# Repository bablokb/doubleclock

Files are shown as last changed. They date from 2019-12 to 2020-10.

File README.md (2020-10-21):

Kitchen-Clock with two countdown-timers (based on TM1637-displays)
==================================================================

Overview
--------

This project implements a double countdown clock (kitchen-timer) using
two TM1637 displays (and some additional components, see below).

The "firmware" uses Python3 and is expected to run on a Raspberry Pi Zero
(or a similar SBC). Porting to a MCU should be an easy task if you have
enough experience.

Hardware
--------

The setup uses the following hardware-components:

  - two TM1637 clock displays
  - one 5-way button for setup
  - one normal button for start/stop
  - optional up to four normal buttons for save/restore ("memory"-buttons)
  - one slider
  - one active buzzer

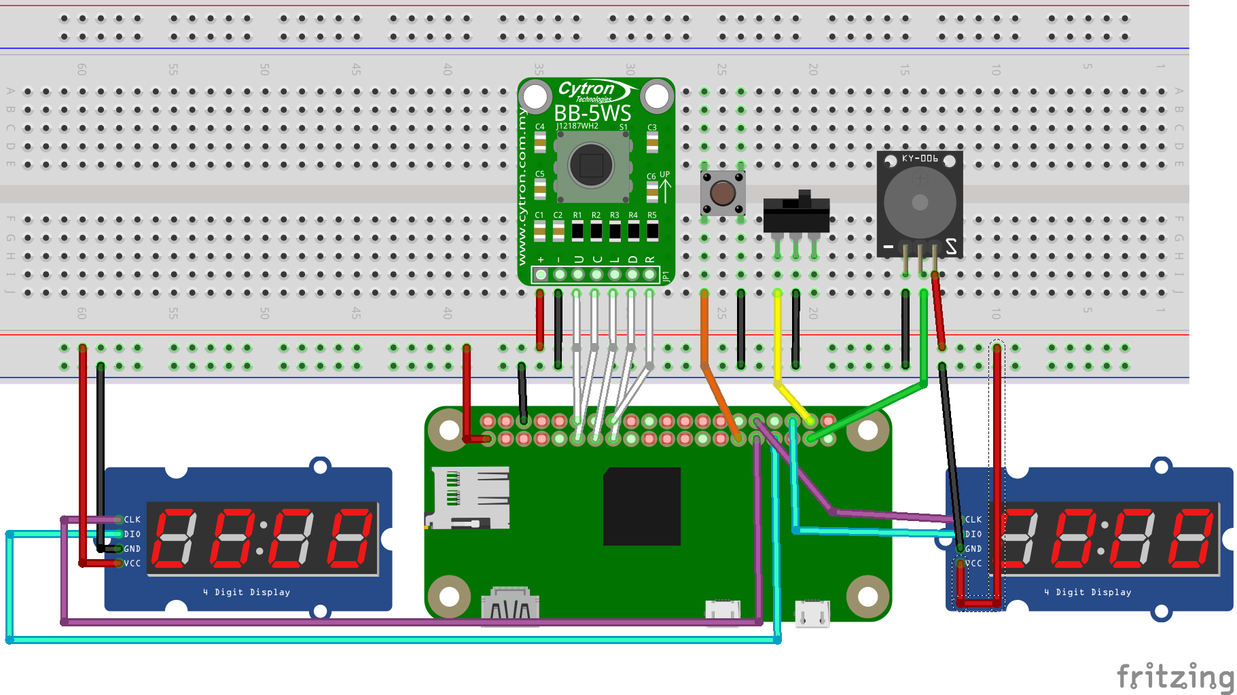
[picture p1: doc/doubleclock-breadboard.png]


You can find details on the necessary wiring in `doc/specs.md`.

This is a prototype using a
[https://github.com/bablokb/pi-proto-hat](https://github.com/bablokb/pi-proto-hat)
as basis:

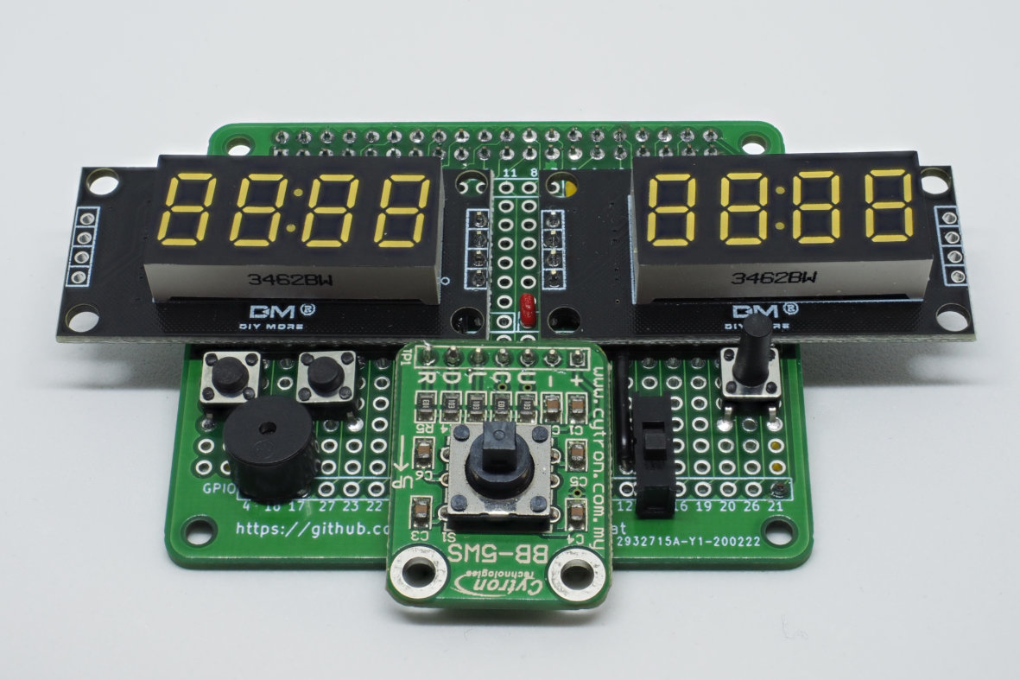
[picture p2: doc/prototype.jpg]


Final version of the case:

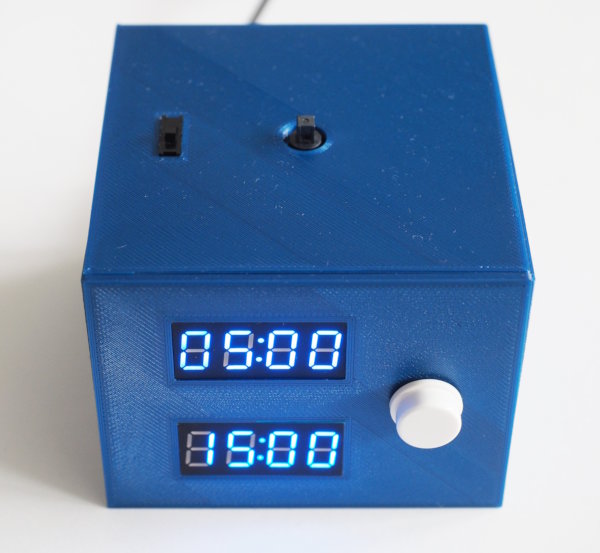
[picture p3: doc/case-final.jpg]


Software
--------

Run

    git clone https://github.com/bablokb/doubleclock.git
    cd doubleclock
    sudo tools/install

to install the software and some prerequisite packages. This will also enable
a systemd-service so that the clock starts at boot-time.

System-Tweaks
-------------

The clock has no shutdown button, so it is best to configure the system
as a readonly-system. If you have a dedicated Pi for the clock, just remove
the lines from `/etc/fstab` which mount `/` and `/boot`.

To speedup boot-time, disable the keyboard-setup.service. Also, add "quiet"
to `/boot/cmdline.txt`. Of course you have to do this before the system is
in readonly-mode.

In readonly-mode, saving the last state and the memory-buttons don't work.
If you want a readonly-system *and* memory-buttons, create a small
data-partition, mount it in `/etc/fstab` with the option `sync` and
replace `/var/lib/doubleclock` with a symbolic link to your mounted
data-partition.

Usage
-----

Push the 5-way button down to enable or disable setup-mode. In setup-mode the
active digit of the active clock will blink. Use the slider to switch between
clocks. Pushing the button to the left or right will change the active digit,
pushing it up or down will change the value. After setting the alarm-times,
push the button down again to leave setup-mode. Note that pressing the
start/stop-button in setup-mode will reset all values to zero.

Use the start/stop-button to activate the countdown. As soon as a clock
reaches zero, the buzzer will start and the brightness of the display is
reduced. Note that after the alarm starts, the display will continue to
count.

In alarm-mode, the start/stop-button will stop the buzzer, but not the second
running clock. Stopping the second alarm will reset the values to the state
after the last setup.

Pressing a memory-button in setup-mode will save the current values. Pressing
them in ready-mode will recall the values. Independent of the memory-buttons,
the clock will save the last values of the clocks.

Case
----

A case (housing) is now available. You can find my tinkercad-project with various parts
[here](https://www.tinkercad.com/things/8dUa6ugfUpZ). You probably need to adapt the
individual parts to your specific components (e.g. to the dimension of your
slider-switch).

The case uses PETG, since PLA is not usable in moist environments like a
kitchen. Also, care has to be taken that no electronic components get wet
when water is spilled on the table. Ideally, the clock would be wall-mounted,
but this is not always possible.

The case should also be easy to open and close, in case a component needs
to be replaced. There are too many throw-away gadgets out in the wild, which
stop working only because a wire gets loose and there is no way to open
the gadget without destroying it. The current case design does not fully meet
these goals.

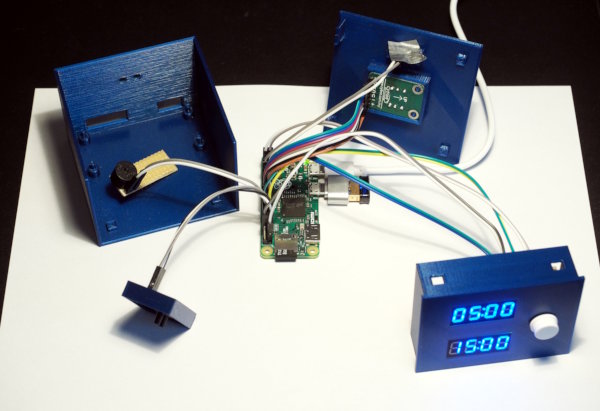
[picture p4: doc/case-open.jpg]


One off the biggest challenges is how to attach the components in a
stable manner. Most of them have either no support at all, or their
mounting holes would result in the breakout to be on the outside.

License
-------

The code in `files/usr/local/sbin/doubleclock.py` is licensed under the GPLv3.

The library in `files/usr/local/sbin/TM1637.py` is from
[https://github.com/bablokb/circuitpython-tm1637](https://github.com/bablokb/circuitpython-tm1637)
and is distributed under a MIT-license.

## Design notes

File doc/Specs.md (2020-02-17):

Technical Specifications
========================

Operation
---------

The *slider* changes between the two clocks. The 5-way button changes the
clock values. The *start/stop* button starts and stops the countdown and
turns of the buzzer. A long press of *start/stop* resets both clocks.

Up to four memory buttons save/recall the current values. Pressing a
memory button while in setup-state will save the values. Pressing the button
in ready-state will recall the values.

The clocks display a countdown in the format "MM:SS" with MM ranging from
0-99 and seconds from 0-59.

States
------

Possible states:

  - *init*: both clocks show "00:00"
  - *setup*: one digit of the active clock is blinking
  - *ready*: one or both clocks are ready to run
  - *running*: one or both clocks are running
  - *alarm*: the buzzer is ringing

Transitions
-----------

  - *init*    + *set/push*   -> *setup*
  - *setup*   + *set/push*   -> *ready*
  - *setup*   + *left/right* -> *setup* (change digit)
  - *setup*   + *up/down*    -> *setup* (increase/decrease value of digit)
  - *setup*   + *start*      -> *init*
  - *ready*   + *start/stop* -> *running*
  - *running* + *start/stop* -> *ready*
  - *alarm*   + *start/stop* -> *running* (stop buzzer) or *ready*

Pin Configuration
-----------------

This is just for information and might not be up-to-date. The truth is
in the code (file `doubleclock.py`).

| Function | Pi-Zero |
|---|---|
| set (push) | 17 |
| up | 18 |
| down | 22 |
| left | 27 |
| right | 23 |
| slider (left) | 20 |
| start/stop | 05 |
| clock (left,clk)  | 06 |
| clock (left,dio)  | 13 |
| clock (right,clk) | 12 |
| clock (right,dio) | 16 |
| buzzer | 26 |
| mem1 | 09 |
| mem2 | 25 |
| mem3 | 11 |
| mem4 | 08 |

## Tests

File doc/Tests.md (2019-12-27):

Tests
=====

  * startup: all digits show 0 (ok)
  * push: rightmost digits blinks on the side of the slider (ok)
  * up/down: blinking digit changes value (ok)
  * left/right: blinking digit moves left/right (ok)
  * slider: blinking digit changes side (ok)
  * slider: blinking digit changes back (ok)
  * start during setup: clear all values and reset (ok)
  * push: digits stop blinking (ok)
  * start: countdown starts (ok)
  * start (again): cancel countdown, show alarm-times (ok)
  * alarm1 on + start: stop buzzer, countdown continues (ok)
  * alarm1 on: buzzer stops automatically (ok)
  * alarm2 on + start: stop buzzer, show alarm-times (ok)
  * single alarm countdown left: countdown, alarm, auto-stop (ok)
  * single alarm countdown rigt: countdown, alarm (ok)

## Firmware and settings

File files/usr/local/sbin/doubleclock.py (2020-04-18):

#!/usr/bin/python3
# -*- coding: utf-8 -*-
# ----------------------------------------------------------------------------
# Countdown-clock with two clocks
#
# Author: Bernhard Bablok
# License: GPL3
#
# Website: https://github.com/bablokb/doubleclock
#
# ----------------------------------------------------------------------------

import threading, signal, os, sys, time, pickle
import TM1637
import board
import RPi.GPIO as GPIO

# --- file for persistent configuration   ------------------------------------

DATA_DIR = "/var/lib/doubleclock"

# --- pin-configuration   ----------------------------------------------------

PIN_PUSH      = 17
PIN_UP        = 18
PIN_DOWN      = 22
PIN_LEFT      = 27
PIN_RIGHT     = 23
PIN_SLIDER_L  = 20
PIN_START     =  5

# set values to zero if unused
PIN_MEM1      =  9
PIN_MEM2      = 25
PIN_MEM3      = 11
PIN_MEM4      =  8

PIN_LCLOCK_C  = board.D6
PIN_LCLOCK_D  = board.D13
PIN_RCLOCK_C  = board.D12
PIN_RCLOCK_D  = board.D16

PIN_BUZZER    = 26
PIN_BUZZER_ON = GPIO.LOW                   # change to GPIO.HIGH if necessary

# --- application-class   ----------------------------------------------------

class DoubleClock(object):

  _STATE_INIT    = 0
  _STATE_SETUP   = 1
  _STATE_READY   = 2
  _STATE_RUNNING = 3
  _STATE_ALARM   = 4
  _BUZZ_WARN     = (0.25,1)                # (duration,repeat)
  _BUZZ_ALARM    = [(0.25,20),(0.5,-1)]    # second alarm runs indefinitely
  _BRIGHTNESS    = 7                       # maximum brightness
  
  # --- constructor   --------------------------------------------------------

  def __init__(self):
    """ constructor """

    self._exit_ev  = threading.Event()         # exit event
    self._count_ev = threading.Event()         # countdown
    self._buzz_ev  = threading.Event()         # buzzer
    self._buzz_thread  = None
    self._clocks   = [                         # left-clock: index is 0
        TM1637.TM1637(PIN_LCLOCK_C,PIN_LCLOCK_D),
        TM1637.TM1637(PIN_RCLOCK_C,PIN_RCLOCK_D)
      ]

    GPIO.setmode(GPIO.BCM)

    GPIO.setup(PIN_PUSH,     GPIO.IN)
    GPIO.setup(PIN_UP,       GPIO.IN)
    GPIO.setup(PIN_DOWN,     GPIO.IN)
    GPIO.setup(PIN_LEFT,     GPIO.IN)
    GPIO.setup(PIN_RIGHT,    GPIO.IN)
    GPIO.setup(PIN_SLIDER_L, GPIO.IN,  pull_up_down=GPIO.PUD_UP)
    GPIO.setup(PIN_START,    GPIO.IN,  pull_up_down=GPIO.PUD_UP)
    GPIO.setup(PIN_BUZZER,   GPIO.OUT, initial=1-PIN_BUZZER_ON)

    GPIO.add_event_detect(PIN_PUSH,     GPIO.FALLING,      self.on_push)
    GPIO.add_event_detect(PIN_UP,       GPIO.FALLING,        self.on_up)
    GPIO.add_event_detect(PIN_DOWN,     GPIO.FALLING,      self.on_down)
    GPIO.add_event_detect(PIN_LEFT,     GPIO.FALLING,      self.on_left)
    GPIO.add_event_detect(PIN_RIGHT,    GPIO.FALLING,     self.on_right)
    GPIO.add_event_detect(PIN_SLIDER_L, GPIO.BOTH,       self.on_slider)
    GPIO.add_event_detect(PIN_START,    GPIO.FALLING, self.on_start,200)

    for pin in [PIN_MEM1,PIN_MEM2,PIN_MEM3,PIN_MEM4]:
      if pin:
        GPIO.setup(pin,GPIO.IN,pull_up_down=GPIO.PUD_UP)
        GPIO.add_event_detect(pin,GPIO.FALLING, self.on_mem,200)

    self._reset()
    self._restore()

  # --- reset internal state   -----------------------------------------------

  def _reset(self):
    self._state    = DoubleClock._STATE_INIT   # global state
    self._values   = [[0,0,0,0], [0,0,0,0]]    # digit-values
    self._dig_nr   = [0,0]                     # current digit-number
    self._clock_nr = GPIO.input(PIN_SLIDER_L)  # current "active" clock
    
  # --- restore clock-values from persistent storage   -----------------------

  def _restore(self,pin=None):
    if pin:
      data_file = os.path.join(DATA_DIR,"mem%d.data" % pin)
    else:
      data_file = os.path.join(DATA_DIR,"last.data")
    try:
      with open(data_file,"rb") as f:
        self._values = pickle.load(f)
    except:
      pass
    if self._values != [[0,0,0,0],[0,0,0,0]]:
      self._state = DoubleClock._STATE_READY
      if pin:
        self._save()

  # --- save clock-values to persistent storage   ----------------------------

  def _save(self,pin=None):
    """ save values - might fail if system is read-only """
    if pin:
      data_file = os.path.join(DATA_DIR,"mem%d.data" % pin)
    else:
      data_file = os.path.join(DATA_DIR,"last.data")
    try:
      with open(data_file,"wb") as f:
        pickle.dump(self._values,f)
    except:
      pass

  # --- process set (push)   -------------------------------------------------

  def on_push(self,pin):
    if self._state == DoubleClock._STATE_INIT:
      self._state = DoubleClock._STATE_SETUP
    elif self._state == DoubleClock._STATE_SETUP:
      self._save()
      self._state = DoubleClock._STATE_READY
    elif self._state == DoubleClock._STATE_READY:
      self._state = DoubleClock._STATE_SETUP

  # --- process left   -------------------------------------------------------

  def on_left(self,pin):
    if not self._state == DoubleClock._STATE_SETUP:
      self.buzz(*DoubleClock._BUZZ_WARN)
    else:
      self._dig_nr[self._clock_nr] = (self._dig_nr[self._clock_nr] + 1) % 4

  # --- process right   ------------------------------------------------------

  def on_right(self,pin):
    if not self._state == DoubleClock._STATE_SETUP:
      self.buzz(*DoubleClock._BUZZ_WARN)
    else:
      self._dig_nr[self._clock_nr] = (self._dig_nr[self._clock_nr] + 3) % 4

  # --- process up   ---------------------------------------------------------

  def on_up(self,pin):
    if not self._state == DoubleClock._STATE_SETUP:
      self.buzz(*DoubleClock._BUZZ_WARN)
      return

    clock = self._clock_nr
    digit = self._dig_nr[clock]
    old   = self._values[clock][digit]
    if digit == 1:
      # 10-seconds
      self._values[clock][digit] = (old+1) % 6
    else:
      # 1-seconds, 1-minutes, 10-minutes
      self._values[clock][digit] = (old+1) % 10

  # --- process down   -------------------------------------------------------

  def on_down(self,pin):
    if not self._state == DoubleClock._STATE_SETUP:
      self.buzz(*DoubleClock._BUZZ_WARN)
      return

    clock = self._clock_nr
    digit = self._dig_nr[clock]
    old   = self._values[clock][digit]
    if digit == 1:
      # 10-seconds
      self._values[clock][digit] = (old+5) % 6
    else:
      # 1-seconds, 1-minutes, 10-minutes
      self._values[clock][digit] = (old+9) % 10

  # --- process start   ------------------------------------------------------

  def on_start(self,pin):
    if self._state == DoubleClock._STATE_INIT:
      # not supported, just buzz
      self.buzz(*DoubleClock._BUZZ_WARN)

    elif self._state == DoubleClock._STATE_SETUP:
      # reset digits during setup-mode
      self._reset()
      self._save()

    elif self._state == DoubleClock._STATE_READY:
      # start alarms

      # calculate seconds per clock ...
      self._secs = [0,0]
      for i in range(2):
        self._secs[i] = (10*60*self._values[i][3] + 60*self._values[i][2] +
                         10*self._values[i][1] +    self._values[i][0])
      
      if self._secs[0] + self._secs[1] > 0:
        self._count_ev.clear()
        self._state    = DoubleClock._STATE_RUNNING
        # ... and start alarm-thread
        threading.Thread(target=self._count).start()

    elif self._state == DoubleClock._STATE_RUNNING:
      # stop countdown and reset to ready-state
      self._count_ev.set()
      self._state = DoubleClock._STATE_READY

    elif self._state == DoubleClock._STATE_ALARM:
      # turn off buzzer
      self._buzz_ev.set()
      if self._secs[0] <= 0 and self._secs[1] <= 0:
        # both alarms are finished, so stop count-down
        self._state = DoubleClock._STATE_READY
        self._count_ev.set()
      else:
        # one alarm is still running
        self._state = DoubleClock._STATE_RUNNING

  # --- process exit   -------------------------------------------------------

  def on_exit(self):
    self._count_ev.set()
    self._buzz_ev.set()
    self._exit_ev.set()

  # --- process slider   -----------------------------------------------------

  def on_slider(self,pin):
    self._clock_nr = GPIO.input(PIN_SLIDER_L)

  # --- process memx-buttons   -----------------------------------------------

  def on_mem(self,pin):
    if self._state == DoubleClock._STATE_SETUP:
      # save values to mem-pinnr
      self._save(pin)
    elif (self._state == DoubleClock._STATE_INIT or
                                     self._state == DoubleClock._STATE_READY):
      self._restore(pin)
    else:
      # not supported, just buzz
      self.buzz(*DoubleClock._BUZZ_WARN)

  # --- ring the buzzer   ----------------------------------------------------

  def buzz(self,duration,count=1):
    if self._buzz_thread:                # buzzer already buzzing
      return
    self._buzz_ev.clear()
    self._buzz_thread = threading.Thread(
      target=self._buzz,args=(duration,count))
    self._buzz_thread.start()

  # --- run the main thread   ------------------------------------------------

  def run(self):
    threading.Thread(target=dclock._update).start()

  # --- update the clock-chips   ---------------------------------------------

  def _update(self):
    """ we update every 0.5 secs to implement blinking """

    blink_off = False
    while True:
      t1 = time.monotonic()
      if self._state in [DoubleClock._STATE_ALARM,DoubleClock._STATE_RUNNING]:
        # update using self._secs
        for i in [0,1]:
          (m,s) = divmod(abs(self._secs[i]),60)
          self._clocks[i].numbers(m,s)
          if not self._secs[i]:
            # timer reached zero, so dim display
            self._clocks[i].brightness(0)
      else:
        # update using self._values
        for i in [0,1]:
          self._clocks[i].brightness(DoubleClock._BRIGHTNESS)
          # copy array of int to array of strings
          val = [str(self._values[i][j]) for j in range(3,-1,-1)]
          if (self._state == DoubleClock._STATE_SETUP and blink_off and
                                                          self._clock_nr == i):
            # the current digit of active clock will blink
            val[3-self._dig_nr[i]] = " "
          digits = "%s%s%s%s" % (*val,)
          self._clocks[i].show(digits,True)
        blink_off = not blink_off

      # wait up to 0.5 seconds (take time lost in logic into account)
      delay = max(0.0,0.5-(time.monotonic()-t1))
      if self._exit_ev.wait(delay):
        break

    # cleanup (clear displays)
    for i in [0,1]:
      self._clocks[i].show(" "*4,False)

  # --- ring the buzzer   ----------------------------------------------------

  def _buzz(self,duration,count):
    """ passing count=-1 will sound the buffer indefintely """

    while count != 0:
      GPIO.output(PIN_BUZZER,PIN_BUZZER_ON)   # buzzer on
      if self._buzz_ev.wait(duration):        # wait and check for interrupt
        break
      GPIO.output(PIN_BUZZER,1-PIN_BUZZER_ON) # buzzer off
      if self._buzz_ev.wait(duration):        # wait and check for interrupt
        break
      count -= 1
    GPIO.output(PIN_BUZZER,1-PIN_BUZZER_ON)   # buzzer off
    self._buzz_thread = None

  # --- count down the remaining seconds   -----------------------------------

  def _count(self):
    """ count down both clocks, exit on external event """

    # we don't want to count-down a clock which is already 0 at start
    use_clock = [self._secs[0] > 0, self._secs[1] > 0]

    # count-down the seconds and sleep inbetween
    while True:
      t1 = time.monotonic()
      if self._state in [DoubleClock._STATE_ALARM,DoubleClock._STATE_RUNNING]:
        for i in [0,1]:
          if use_clock[i]:
            self._secs[i] -= 1
            if not self._secs[i]:
              # countdown reached zero, so stop old and start new alarm
              if self._buzz_thread:
                self._buzz_ev.set()
                try:
                  self._buzz_thread.join()
                except:
                  pass
              self._state = DoubleClock._STATE_ALARM
              self.buzz(*DoubleClock._BUZZ_ALARM[i])

      # wait up to one second (take time lost in logic into account)
      delay = max(0.0,1-(time.monotonic()-t1))

      if self._count_ev.wait(delay):
        return

# --------------------------------------------------------------------------

def signal_handler(_signo, _stack_frame):
  """ Signal-handler to cleanup threads """

  global dclock
  dclock.on_exit()
  sys.exit(0)

# --------------------------------------------------------------------------

if __name__ == "__main__":

  # create objects and run update thread
  dclock = DoubleClock()
  dclock.run()

  # setup signal handlers
  signal.signal(signal.SIGTERM, signal_handler)
  signal.signal(signal.SIGINT, signal_handler)

  # --- main loop   ---------------------------------------------------------

  signal.pause()

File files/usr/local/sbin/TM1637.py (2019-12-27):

"""
MicroPython TM1637 quad 7-segment LED display driver
https://github.com/mcauser/micropython-tm1637

MIT License
Copyright (c) 2016 Mike Causer

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
import digitalio
import time

class TM1637(object):
  """Library for quad 7-segment LED modules based on the TM1637 LED driver."""

  _CMD1   = 0x40      # data command
  _CMD2   = 0xC0      # address command
  _CMD3   = 0x80      # display control command
  _DSP_ON = 0x08      # display on
  _DELAY  = 0.000010  # 10us delay between clk/dio pulses
  _MSB    = 0x80      # decimal point or colon depending on your display

  # 0-9, a-z, blank, dash, star
  _SEGMENTS = bytearray(b'\x3F\x06\x5B\x4F\x66\x6D\x7D\x07\x7F\x6F\x77\x7C\x39\x5E\x79\x71\x3D\x76\x06\x1E\x76\x38\x55\x54\x3F\x73\x67\x50\x6D\x78\x3E\x1C\x2A\x76\x6E\x5B\x00\x40\x63')

  def __init__(self, clk, dio, brightness=7):
    if not 0 <= brightness <= 7:
      raise ValueError("Brightness out of range")
    self._brightness = brightness

    self._clk = digitalio.DigitalInOut(clk)
    self._clk.direction = digitalio.Direction.OUTPUT
    self._clk.value     = 0
    self._dio = digitalio.DigitalInOut(dio)
    self._dio.direction = digitalio.Direction.OUTPUT
    self._dio.value     = 0
    time.sleep(TM1637._DELAY)
    self._write_data_cmd()
    self._write_dsp_ctrl()

  def _start(self):
    self._dio.value = 0
    time.sleep(TM1637._DELAY)
    self._clk.value = 0
    time.sleep(TM1637._DELAY)

  def _stop(self):
    self._dio.value = 0
    time.sleep(TM1637._DELAY)
    self._clk.value = 1
    time.sleep(TM1637._DELAY)
    self._dio.value = 1

  def _write_data_cmd(self):
    # automatic address increment, normal mode
    self._start()
    self._write_byte(TM1637._CMD1)
    self._stop()

  def _write_dsp_ctrl(self):
    # display on, set brightness
    self._start()
    self._write_byte(TM1637._CMD3 | TM1637._DSP_ON | self._brightness)
    self._stop()

  def _write_byte(self, b):
    for i in range(8):
      self._dio.value = (b >> i) & 1
      time.sleep(TM1637._DELAY)
      self._clk.value = 1
      time.sleep(TM1637._DELAY)
      self._clk.value = 0
      time.sleep(TM1637._DELAY)
    self._clk.value = 0
    time.sleep(TM1637._DELAY)
    self._clk.value = 1
    time.sleep(TM1637._DELAY)
    self._clk.value = 0
    time.sleep(TM1637._DELAY)

  def brightness(self, val=None):
    """Set the display brightness 0-7."""
    # brightness 0 = 1/16th pulse width
    # brightness 7 = 14/16th pulse width
    if val is None:
      return self._brightness
    if not 0 <= val <= 7:
      raise ValueError("Brightness out of range")

    self._brightness = val
    self._write_data_cmd()
    self._write_dsp_ctrl()

  def write(self, segments, pos=0):
    """Display up to 6 segments moving right from a given position.
    The MSB in the 2nd segment controls the colon between the 2nd
    and 3rd segments."""
    if not 0 <= pos <= 5:
      raise ValueError("Position out of range")
    self._write_data_cmd()
    self._start()

    self._write_byte(TM1637._CMD2 | pos)
    for seg in segments:
      self._write_byte(seg)
    self._stop()
    self._write_dsp_ctrl()

  def encode_digit(self, digit):
    """Convert a character 0-9, a-f to a segment."""
    return TM1637._SEGMENTS[digit & 0x0f]

  def encode_string(self, string):
    """Convert an up to 4 character length string containing 0-9, a-z,
    space, dash, star to an array of segments, matching the length of the
    source string."""
    segments = bytearray(len(string))
    for i in range(len(string)):
      segments[i] = self.encode_char(string[i])
    return segments

  def encode_char(self, char):
    """Convert a character 0-9, a-z, space, dash or star to a segment."""
    o = ord(char)
    if o == 32:
      return TM1637._SEGMENTS[36] # space
    if o == 42:
      return TM1637._SEGMENTS[38] # star/degrees
    if o == 45:
      return TM1637._SEGMENTS[37] # dash
    if o >= 65 and o <= 90:
      return TM1637._SEGMENTS[o-55] # uppercase A-Z
    if o >= 97 and o <= 122:
      return TM1637._SEGMENTS[o-87] # lowercase a-z
    if o >= 48 and o <= 57:
      return TM1637._SEGMENTS[o-48] # 0-9
    raise ValueError("Character out of range: {:d} '{:s}'".format(o, chr(o)))

  def hex(self, val):
    """Display a hex value 0x0000 through 0xffff, right aligned."""
    string = '{:04x}'.format(val & 0xffff)
    self.write(self.encode_string(string))

  def number(self, num):
    """Display a numeric value -999 through 9999, right aligned."""
    # limit to range -999 to 9999
    num = max(-999, min(num, 9999))
    string = '{0: >4d}'.format(num)
    self.write(self.encode_string(string))

  def numbers(self, num1, num2, colon=True):
    """Display two numeric values -9 through 99, with leading zeros
    and separated by a colon."""
    num1 = max(-9, min(num1, 99))
    num2 = max(-9, min(num2, 99))
    segments = self.encode_string('{0:0>2d}{1:0>2d}'.format(num1, num2))
    if colon:
      segments[1] |= 0x80 # colon on
    self.write(segments)

  def temperature(self, num):
    if num < -9:
      self.show('lo') # low
    elif num > 99:
      self.show('hi') # high
    else:
      string = '{0: >2d}'.format(num)
      self.write(self.encode_string(string))
    self.write([TM1637._SEGMENTS[38], TM1637._SEGMENTS[12]], 2) # degrees C

  def show(self, string, colon=False):
    segments = self.encode_string(string)
    if len(segments) > 1 and colon:
      segments[1] |= 128
    self.write(segments[:4])

  def scroll(self, string, delay=250):
    segments = string if isinstance(string, list) else self.encode_string(string)
    data = [0] * 8
    data[4:0] = list(segments)
    for i in range(len(segments) + 5):
      self.write(data[0+i:4+i])
      sleep_ms(delay)

# ---------------------------------------------------------------------------

class TM1637Decimal(TM1637):
  """Library for quad 7-segment LED modules based on the TM1637 LED driver.

  This class is meant to be used with decimal display modules (modules
  that have a decimal point after each 7-segment LED).
  """

  def encode_string(self, string):
    """Convert a string to LED segments.

    Convert an up to 4 character length string containing 0-9, a-z,
    space, dash, star and '.' to an array of segments, matching the length of
    the source string."""
    segments = bytearray(len(string.replace('.','')))
    j = 0
    for i in range(len(string)):
      if string[i] == '.' and j > 0:
        segments[j-1] |= TM1637._MSB
        continue
      segments[j] = self.encode_char(string[i])
      j += 1
    return segments

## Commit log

2019-12-27 bugfix: on_start(): state PAUSE does not exist anymore
    [doubleclock.py]
2020-01-01 removed redundant right pin of slider (PIN_SLIDER_R)
2020-01-14 added config-variable for buzzer-on
    [doubleclock.py]
2020-02-08 change permissions of doubleclock.mount_helper
2020-02-17 added specs for memory-buttons
2020-02-21 implement memory-buttons
2020-02-21 document memory-buttons
2020-04-03 added section 'Case'
2020-04-18 minor changes
    [doubleclock.fzz]
2020-04-18 support PIN_MEMx = 0 for unconnected memory-buttons
2020-05-17 moved prototype-image to doc
2020-05-17 link to prototype-image
2020-10-05 removed chmod for non-existent mount_helper
2020-10-21 link images of case
